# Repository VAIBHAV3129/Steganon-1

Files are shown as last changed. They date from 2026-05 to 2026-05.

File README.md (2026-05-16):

# Steganon-1

Steganon-1-2

----------------------------------------------

Steganon is a really advanced, dual-node P2P encrypted communication terminal designed for secure data transmission in off-grid or urban environments where privacy is compromised. It is built around the high-performance Raspberry Pi RP2350 (Pico 2) microcontroller, the system leverages LoRa radio technology to facilitate decentralized, long-range text messaging and sensor data exchange without the need for cellular or internet infrastructure facilities.

# Project Workflow



# Wiring Schematic



Pleaase note that the Kicad schematic contains only a few basic and vital components, since I was unable to find the rest

# BOM

##  Bill of Materials (BOM)

| Component | Function | Quantity |
| :--- | :--- | :---: |
| **Raspberry Pi Pico 2W** | Core Logic & Encryption (RP2350) | 2 |
| **RFM95W LoRa Module** | 866MHz Long-Range Communication | 2 |
| **NEO-M9N GNSS** | Location Tagging & Time-Sync | 2 |
| **1.3" I2C OLED** | User Interface & Message Display | 2 |
| **4x4 Matrix Keypad** | Manual Data & Cipher Entry | 2 |
| **TP4056 Module** | Li-Ion Battery Charging & Protection | 2|
| **MT3608 Converter** | 5V Boost Rail (GPS/OLED) | 2 |
| **AMS1117-3.3V** | 3.3V Logic Regulator (Pico/Radio) | 2 |
| **18650 Battery** | 3.7V Mobile Power Source | 4 |
| **SMA Antenna** | High-Gain 866MHz RF Interface | 2 |

# Abstract Project Visualisation

Of only some of the basic components



-------------------------------------------------------------

Banner Image - Canva

Schematics - Kicad

Flowchart - Excalidraw

CAD - Onshape

Project Visualization Image - AI Assisted

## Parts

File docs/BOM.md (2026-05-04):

# Steganon-1 Bill of Materials (BOM)

| Category | Component Item | Qty | Specification  |
| --- | --- | --- | --- |
| **Compute** | Raspberry Pi Pico 2W (RP2350) | 2 | Dual-core ARM Cortex-M33; handles AES-256 and UI |
| **Radio** | Grove RFM95 LoRa Module | 2 | 865-867MHz (Configured for India ISM Band) |
| **Positioning** | SmartElex NEO-M9N GNSS | 2 | Concurrent 4 GNSS reception with SMA connector|
| **Display** | 1.3 inch I2C OLED Module | 2 | 128x64 Blue Monochrome status display |
| **Input** | 4x4 Matrix Keypad Module | 2 | 16-button interface for secure message entry |
| **Storage** | DFRobot MicroSD Card Module | 2 | SPI interface for local off-grid message logging |
| **Antenna** | 5dBi LoRa Magnetic Antenna | 2 | High-gain omnidirectional antenna |
| **RF Cable** | SMA to U.FL Cable (20cm) | 2 | Interfaces module U.FL to chassis SMA |
| **Power** | 18650 Li-Ion Battery | 4 | 3.7V 2900mAh power source |
| **Power** | TP4056 Charger Module | 2 | USB-C charging with over-discharge protection |
| **Power** | MT3608 Step-up Converter | 2 | Boosts battery to 5V for GPS/OLED rails |
| **Power** | AMS1117 3.3V Power Module | 2 | LDO regulation for RP2350 and LoRa logic |
| **Audio** | Active Buzzer Module | 2 | Audible alerts for transmission or low battery |

---

### System Integration Summary
* **Dual-Node Strategy**: This BOM provides full components for two complete nodes, enabling point-to-point (P2P) encrypted communication testing.
* **Power Rail Logic**: The **MT3608** provides a 5V rail for the GPS and OLED, while the **AMS1117** ensures a clean 3.3V supply for the RP2350 and LoRa module to prevent frequency drift.
* **Regulatory Compliance**: All radio hardware is selected to operate within the **865–867 MHz** license-free band in India.

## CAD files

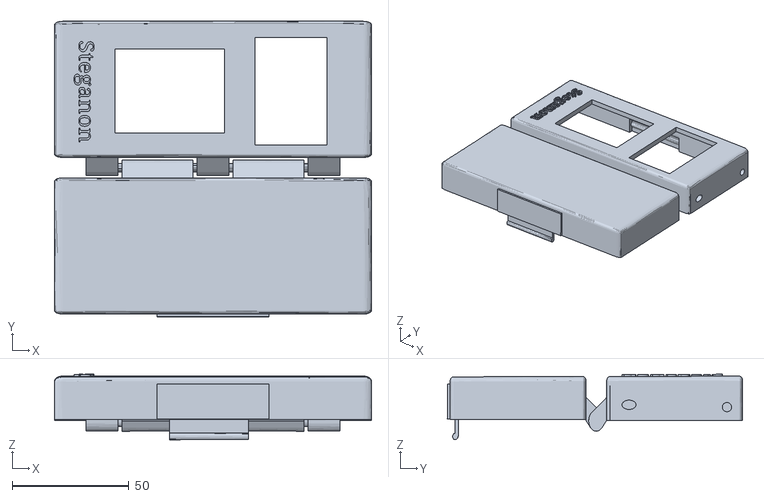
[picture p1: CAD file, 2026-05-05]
hardware/enclosure/enclosure.stl
136.0 x 126.8 x 28.1

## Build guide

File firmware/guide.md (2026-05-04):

## The Steganon-1 Data Path:

- Input: User types a message on the UI (OLED/Buttons).

- Processing: RP2350 fetches GPS coordinates from the NEO-M9N.

- Encryption: RP2350 wraps the message and GPS data in an encrypted packet.

- Output: The RFM95 broadcasts the packet over LoRa frequencies.

The Entire code is written via micropython

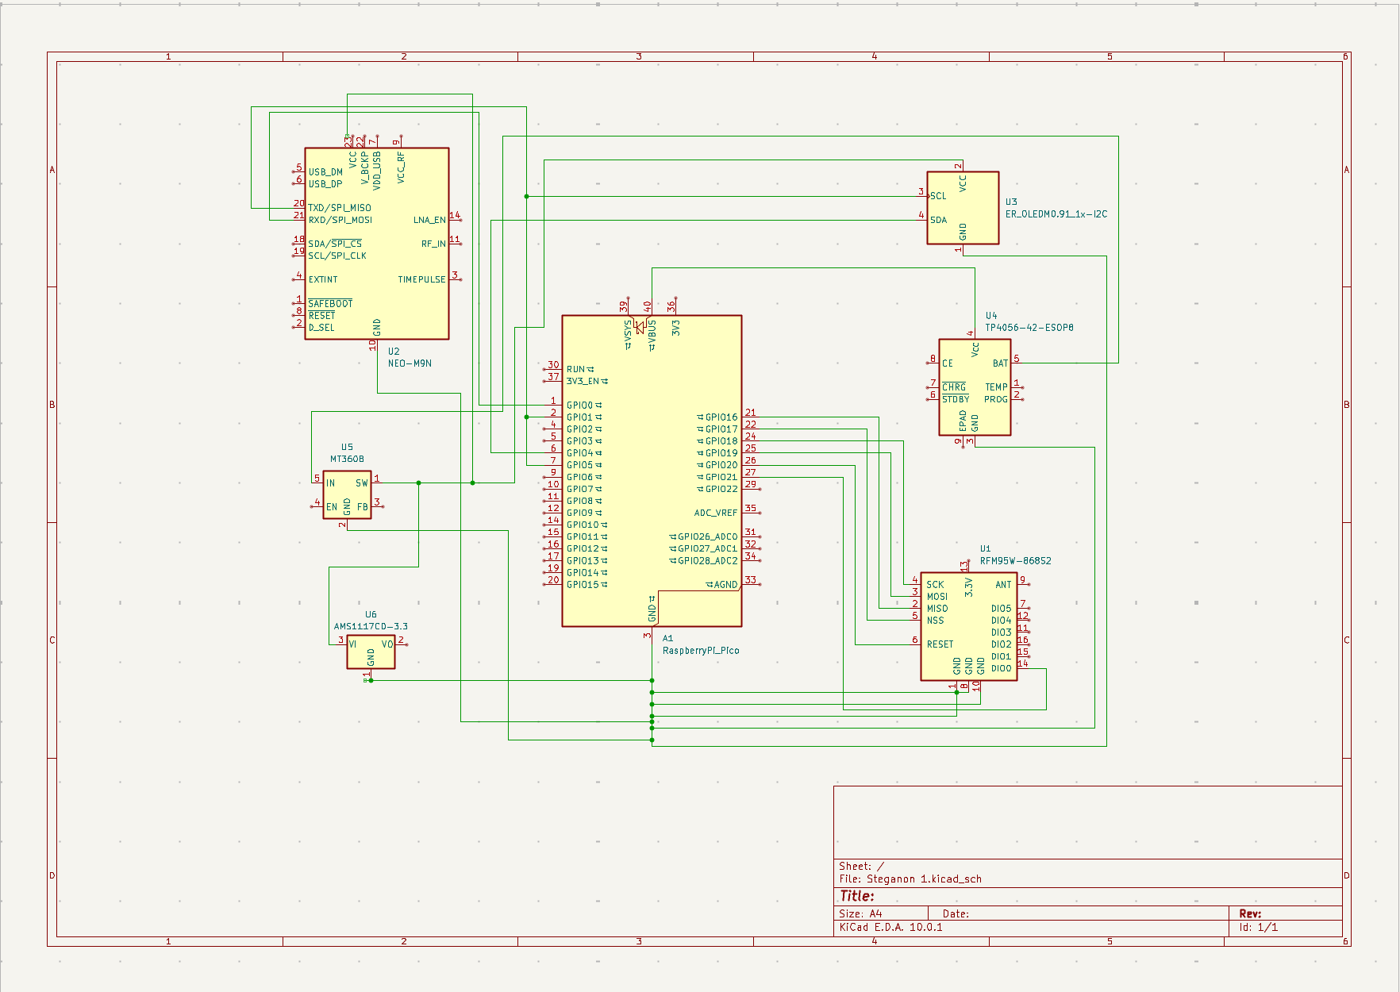
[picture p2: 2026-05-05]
hardware/schematics/Schematics of Wiring.png

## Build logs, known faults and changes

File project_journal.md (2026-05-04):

29 Apr 2026 - Started the project Steganon-1

2 May 2026 - Finalised the plan and BOM, Datasheet Research

3 May 2026 - Prepared the code workflow chart

4 May 2026 - Wrote the starting high level code, in micropython

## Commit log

2026-05-01 Update .gitignore for KiCad project files
    Add common KiCad temporary and backup files to .gitignore
2026-05-01 Enhance .gitignore with additional file exclusions
    Refine ignored files in .gitignore for better clarity and organization, including additions for KiCad and temporary files.
2026-05-01 Create kicad pcb.txt
2026-05-04 Add BOM for Steganon-1 with component details
    Added detailed Bill of Materials (BOM) for Steganon-1 project including component specifications and system integration summary.
2026-05-04 Update power supply quantity for Li-Ion Battery
2026-05-05 Create cad
2026-05-05 Update README with wiring schematic and BOM
    Added detailed wiring schematic and Bill of Materials (BOM) for the Steganon project.
